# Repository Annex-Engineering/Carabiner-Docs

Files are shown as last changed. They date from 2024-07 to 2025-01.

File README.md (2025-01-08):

# Carabiner

The Carabiner-PCBs are a series of toolboards for a quick & easy connection between the backpack and toolhead.

## Different Variants

| Name | Location | Recommended for Printer | 
| --- | --- | --- |
| Carabiner Classic | Toolhead | Any printer |
| K3rabiner | Toolhead | K3 |
| Carabiner K1.5 | Toolhead | K1 / K2 |
| Carabiner Distributor | Backpack | Any printer
| Carabiner Distributor XOL | Backpack | Any printer with a matching XOL Toolhead Board

As an alternative for any Carabiner in the backpack, you can use a Constellation Sirius (coming soon!) to make wiring your Carabiner even easier!

## Features
All variants of Carabiner share the following main features:
- 16-pin input/output via MicroFit connector
- Chamber thermistor
- USB support
- 48V on your heater, hotend-fan and part-cooling fan (if your mainboard allows for it!)

Most variants of the Carabiner also have the following feature:
- Selectable Voltage for partcooling-fan / hotend-fan between the hotend voltage & 1 alternative voltage

## Warnings

Here be dragons - as with everything that involves electronics, make sure to double-check your wiring before powering it on to avoid producing magic smoke & frying components.  
It's recommended to check the following points:
- Both Carabiners have their MicroFit connector plugged in on the same side of the PCB (usually marked as 'Side A').
- Check for shorts between the following pins with your multimeter:
   - Main+ and HE-
   - Main+ and PCF-
   - Main+ and HEF-
   - Alt+ and PCF-
   - Alt+ and HEF-
   - Alt+ and Main+

## Source, PCBs, Gerbers

While I (iKirin), do enjoy releasing most things that I work/worked on as open-source, I've decided to remove the source as well as the gerbers for all current and future revisions of all carabiners.
This is due to a very limited amount of vendors believing, that just because a source is uploaded to Github, they can take the files and make them, even if commercial use is generally not permitted. 
There is no licensing fee charged for any shop that decides to carry the board, however I do kindly ask that they donate a small amount of money per order to reforestation or local communities dedicated to keep the local flora & fauna intact.

If you want to help to get the carabiner from any shop that is officially affiliated, please check out the [sourcing guide](https://docs.google.com/spreadsheets/d/1O3eyVuQ6M4F03MJSDs4Z71_XyNjXL5HFTZr1jsaAtRc/edit?usp=sharing)

## License

Please see the License.md file in this repo

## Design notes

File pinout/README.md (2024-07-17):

# Pinout

All carabiners (& derivatives) are using the official pinout for the carabiner.

We welcome other groups using the cable for their projects, but kindly ask to note in their project page if they are using the official carabiner pinout, to help prevent damage to users equipment, caused by different pinouts.

## Pinout

This pinout assumes you're looking directly at the cable. 

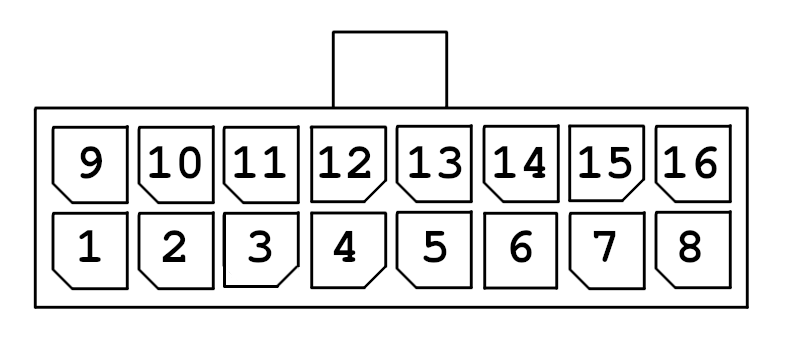
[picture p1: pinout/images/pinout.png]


| PinNumber | Usage  | OnPCB | PinNumber | Usage | OnPCB | 
|---|:---:|:---:| --- |:---:|:---:|
| 1  |  Thermistor Chamber | ThChamb | 9 | Hotend Voltage | Main+
| 2  | Partcooling Fans Ground | PCF- | 10 | Hotend Ground | HE-
| 3  | Hotend Fan Ground | HEF- | 11 | Alt Voltage | Alt+
| 4  | Thermistor Common Ground | ThGnd | 12 | Thermistor Hotend | ThHE
| 5  | Motor A | 1A | 13 | Motor C | 2A
| 6  | Motor B | 1B | 14 | Motor D | 2B
| 7  | Aux 1 | A1 | 15 | Aux 2 | A2
| 8  | Aux 4 | A4 | 16 | Aux 3 | A3

## Recommended Wiregauge

While we have official cables available, we don't want to discourage people making their own cables, as such here is our recommended minimum wiregauge, for making a cable with the official pinout.
These recommendations assume the carabiner is being used in a 50° chamber.

| Pin-Number | Recommended AWG | Recommended mm² |
|:---:|:---:|:---:|
| 1 | 26 | 0.125 |
| 2 | 22 | 0.3 |
| 3 | 26 | 0.125 |
| 4 | 26 | 0.125 |
| 5 | 26 | 0.125 |
| 6 | 26 | 0.125 |
| 7 | 26 | 0.125 |
| 8 | 26 | 0.125 |
| 9 | 22 | 0.3 |
| 10 | 22 | 0.3 |
| 11 | 22 | 0.3 |
| 12 | 26 | 0.125 |
| 13 | 26 | 0.125 |
| 14 | 26 | 0.125 |
| 15 | 26 | 0.125 |
| 16 | 26 | 0.125 |

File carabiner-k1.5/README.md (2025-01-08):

# Carabiner-K1.5

This is a carabiner for either K1 or K2, Rev X.
It has two different versions which only differ by which hotend you're using

## Features

- Input via 16pin horizontal/vertical microfit
- Two outputs for partcooling fans
- Thermistor for the chamber
  - Supports any size from 0603 to 1206

## Other Notes

- Hotend-Fan is always connected to Alt Voltage on Carabiner K1.5
- Partcooling-Fan is always connected to Alt Voltage on Carabiner K1.5

## Connectors & Amperage

_Note: All amperage-values have been designed to work in an enclosed printer with up to 65° chamber temperature & have safety margins. While you could use higher ampere in an open-frame printer, this is not encouraged.<br/>
When multiple connectors are supported **bold** marks the recommended connector._

| | Supported Connectors | Maximum Ampere |
| --- | --- | --- |
| Hotend  | 2-pin JST XH <br/> Microfit 430450227 <br/> **Microfit 436500227** (compatible with e3d heater) | 2 Ampere (40W heater on 24V) <br/> 4.2 Ampere (100W heater on 24V) <br/>4.2 Ampere (100W heater on 24V)
| Hotend Thermistor  | 2-pin JST XH <br/> **Microfit 436500227** (compatible with e3d thermistor) | / <br/> /
| Hotend Fan | 2-pin JST XH | 1 Ampere
| 2x Partcooling Fan | 2-pin JST XH | 1 Ampere (total for both)
| Stepper | 4-pin JST XH | 1.2 Ampere <br/> 0.84 Ampere on TMC drivers as you specify the RMS ampere which is ~70% of peak
| Aux / Probe | 4-pin JST XH | 0.8 Ampere

## BOM / Parts

Links to purchase fully assembled boards can be found here: [ANNEX Sourcing Guide](https://docs.google.com/spreadsheets/d/1aSM1jGxg-s0tyynyR3f8M0IQMXuXw57RJvoJbt98Clw/edit?usp=sharing)

Be aware that the Carabiner K1.5 has 2 options for different hotends.

## Hotends & Versions

<tbd>

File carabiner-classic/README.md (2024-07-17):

# Carabiner-Classic
(Previously known as Carabiner or Carabiner-Toolboard)

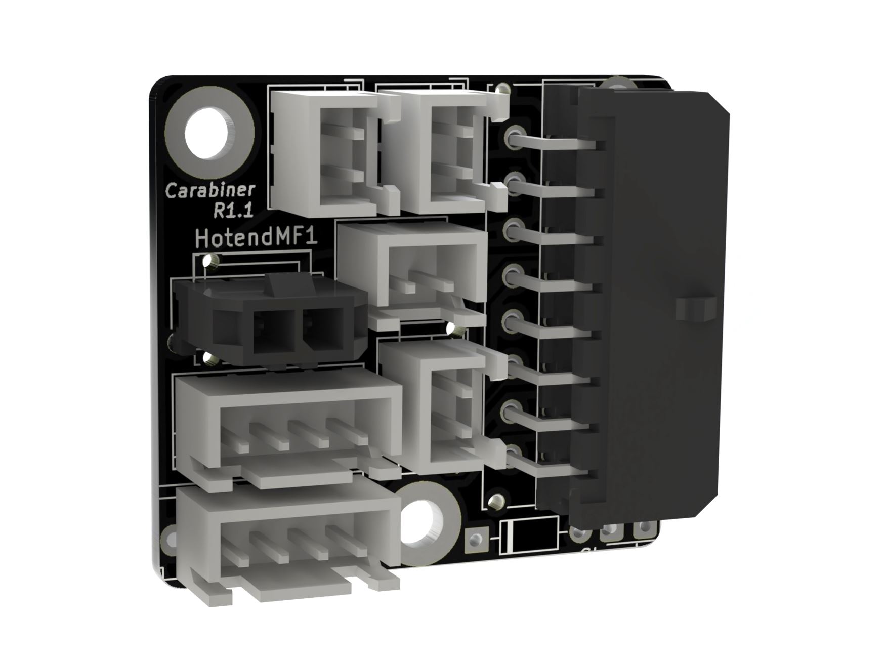
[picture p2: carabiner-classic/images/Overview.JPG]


The carabiner-classic is a toolboard for easy & quick connection between the backpack and toolhead.
It's a generic design, intended to be used a reference and for printers without space constraints.
It was inspired by the first iterations of the dumbboard by LukesLab and designed to bring the idea of a 'simple toolboard' to the next level!

## Features

- Input via 16pin horizontal/vertical microfit
- Two outputs for partcooling fans
- Soldered seperate voltage selection for hotend fan and partcooling fan
   - Uses either the hotend voltage or one alternative voltage
- Thermistor for the chamber
  - Supports any size from 0603 to 1206

## Connectors & Amperage

_Note: All amperage-values have been designed to work in an enclosed printer with up to 65° chamber temperature & have safety margins. While you could use higher ampere in an open-frame printer, this is not encouraged.<br/>
When multiple connectors are supported **bold** marks the recommended connector._

| | Supported Connectors | Maximum Ampere |
| --- | --- | --- |
| Hotend  | 2-pin JST XH <br/> Microfit 430450227 <br/> **Microfit 436500227** (compatible with e3d heater) | 2 Ampere (40W heater on 24V) <br/> 4.2 Ampere (100W heater on 24V) <br/>4.2 Ampere (100W heater on 24V)
| Hotend Thermistor  | 2-pin JST XH <br/> **Microfit 436500227** (compatible with e3d thermistor) | / <br/> /
| Hotend Fan | 2-pin JST XH | 1 Ampere
| 2x Partcooling Fan | 2-pin JST XH | 1 Ampere (total for both)
| Stepper | 4-pin JST XH | 1.2 Ampere <br/> 0.84 Ampere on TMC drivers as you specify the RMS ampere which is ~70% of peak
| Aux / Probe | 4-pin JST XH | 0.8 Ampere

## BOM / Parts

Find the latest BOM in the [Annex Sourcing Guide](https://docs.google.com/spreadsheets/d/1O3eyVuQ6M4F03MJSDs4Z71_XyNjXL5HFTZr1jsaAtRc) under PCBs

## Revisions

The following revisions have been made to the Carabiner-Classic (Previously known as Carabiner).
This overview is non-exhaustive and does not cover all revisions that were previously released.

|Version|Changes|Known Bugs|
|:---|:-----|:---|
|1.3|Remove 5th pin for AUX.<br>Add USB-support on the AUX-port|-|
|1.2.1|-|The second A3 port, after JP_A3 is not connected.|
|1.2|-|The second A3 port, after JP_A3 is not connected.|

## Build Guide

[Please check out this simple written build guide](buildguide/README.md).

## Wiring Guide

[Please refer to the pinout-section of the docs](../pinout/README.md)

## Gallery
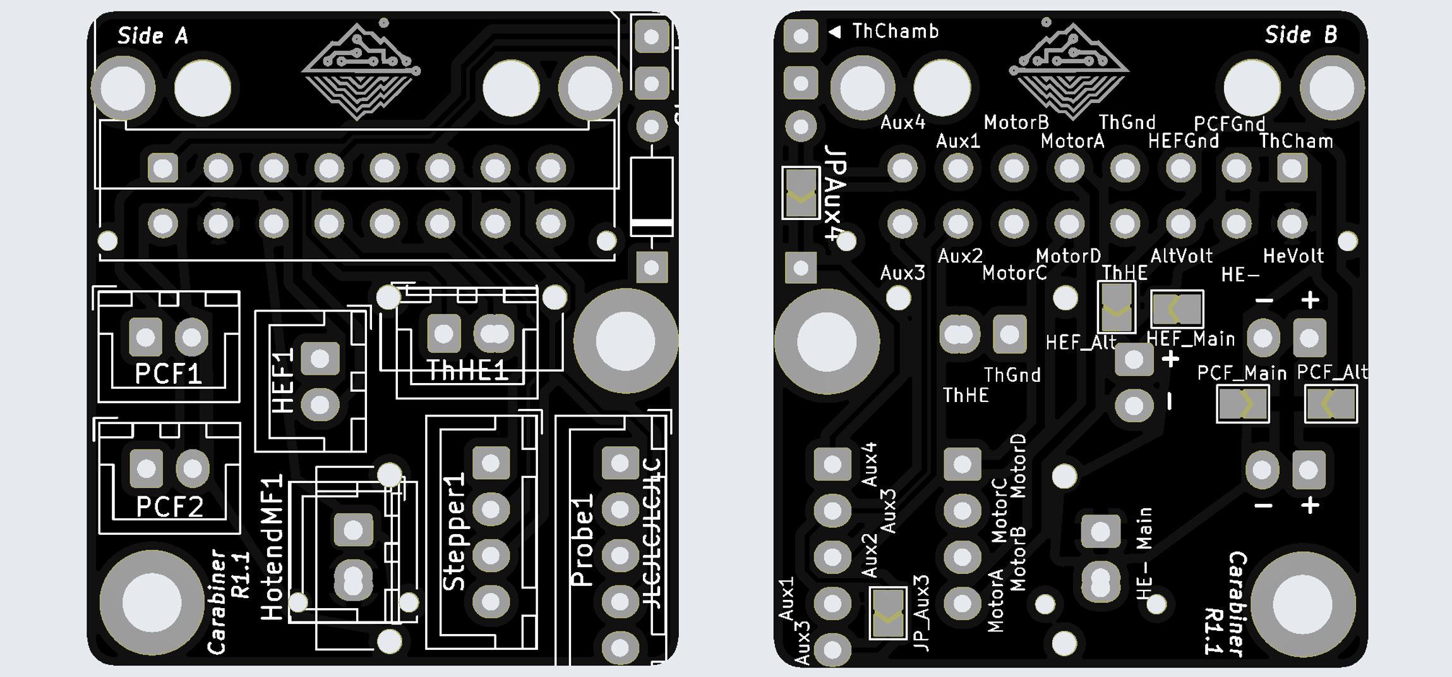
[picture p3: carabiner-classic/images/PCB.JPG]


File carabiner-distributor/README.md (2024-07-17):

# Carabiner Distributor

The distributor variant is a toolboard for the electronics bay providing an easy & quick connection between the electronic controllers and toolhead. 
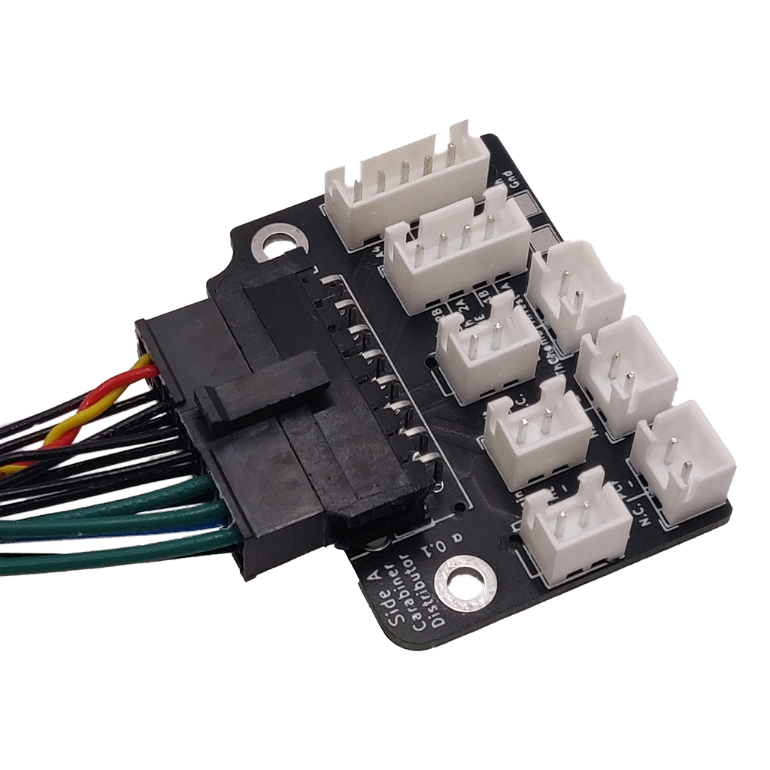
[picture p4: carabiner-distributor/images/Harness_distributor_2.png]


## Features

- Input via 16pin horizontal or vertical microfit
- Testpads for easy thermistor troubleshooting
- Easy to read labeling of the connectors

## Connectors & Amperage

_Note: All amperage-values have been designed to work in an enclosed printer with up to 65° chamber temperature & have  some safety margins. While you could use higher ampere in an open-frame printer, it's highly discouraged. <br/>
When multiple connectors are supported **bold** marks the recommended connector._

| | Supported Connectors | Maximum Ampere |
| --- | --- | --- |
| Hotend  | 2-pin JST XH <br/> Microfit 430450227 <br/> **Microfit 436500227** (compatible with e3d heater) | ~2 Ampere (50W heater on 24V) <br/> 4.2 Ampere (100W heater on 24V) <br/>4.2 Ampere (100W heater on 24V)
| Hotend Thermistor  | 2-pin JST XH <br/> **Microfit 436500227** (compatible with e3d thermistor) | / <br/> /
| Hotend Fan | 2-pin JST XH | 1 Ampere
| Partcooling Fan | 2-pin JST XH | 2 Ampere
| Stepper | 4-pin JST XH | 1.2 Ampere <br/> 0.84 Ampere on TMC drivers as you specify the RMS ampere which is ~70% of peak
| Aux / Probe | 4 or 5-pin JST XH | 0.8 Ampere

## Sourcing

Links to purchase fully assembled boards can be found here: [ANNEX Sourcing Guide](https://docs.google.com/spreadsheets/d/1aSM1jGxg-s0tyynyR3f8M0IQMXuXw57RJvoJbt98Clw/edit?usp=sharing)

Be aware that the distributor pcb has 2 options for connectors regarding the thermistor and heater.

## Using the Testpads

When using both the hotend and chamber thermistor, it is important to ensure that you don't accidentially have the Ground swapped with the Thermistor-Pin.
To validate your thermistors are wired up correctly, it's recommended to use a multimeter and the Testpads on the Distributor.
Connect the Distributor to the mainboard of the printer.
When everything is wired up correctly, the resistance between the two Testpads should be close to 0 Ohms. 
If it does not measure 0 Ohms, please check your wiring and ensure that both ThTest as well as ThGnd are wired to the ThermistorGnd on the mainboard of your printer.

## Revisions

The following revisions have been made to the Carabiner Distributor.
This overview is non-exhaustive and does not cover all revisions that were previously released.

|Version|Changes|Known Bugs|
|:---|:-----|:---|
|1.0|-|-|

## Wiring Guide

[Please refer to the pinout-section of the docs](../pinout/README.md)

## Dimensions
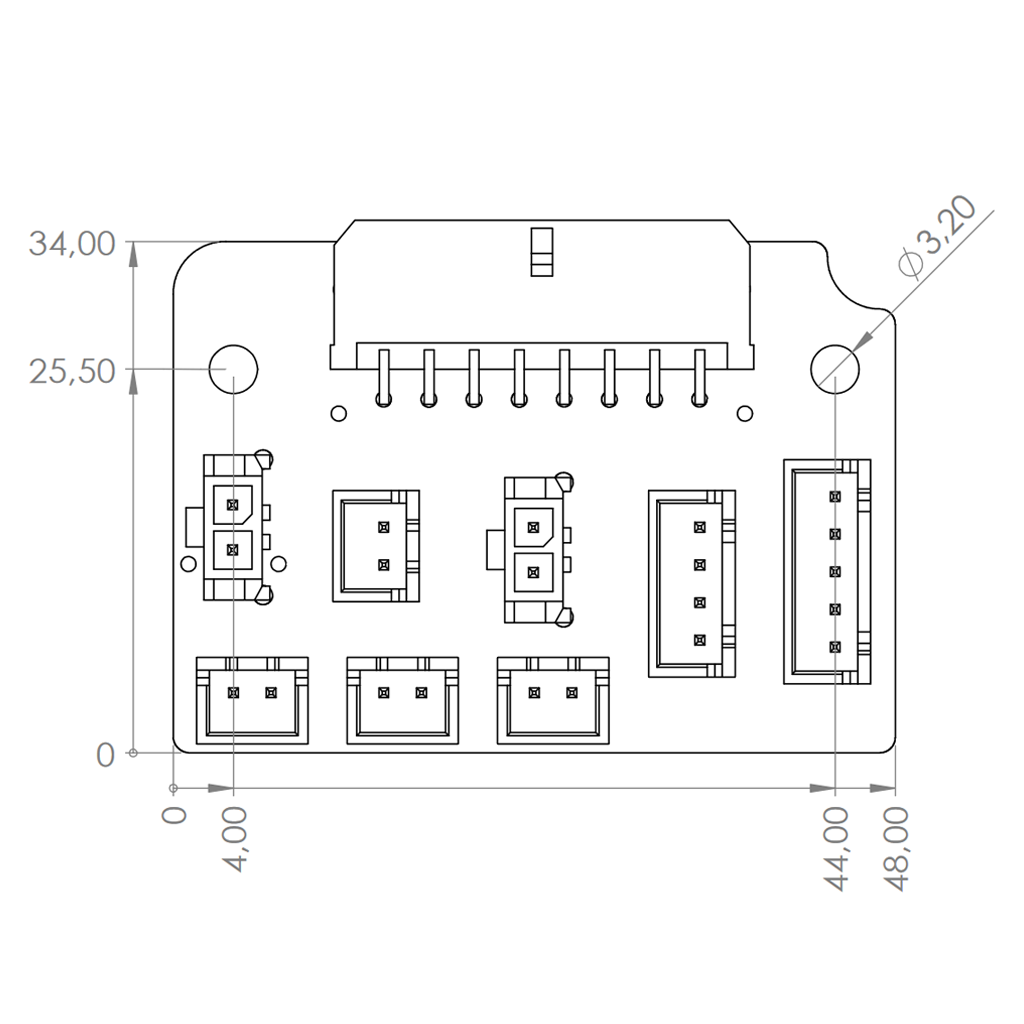
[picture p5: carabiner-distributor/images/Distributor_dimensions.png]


## Gallery
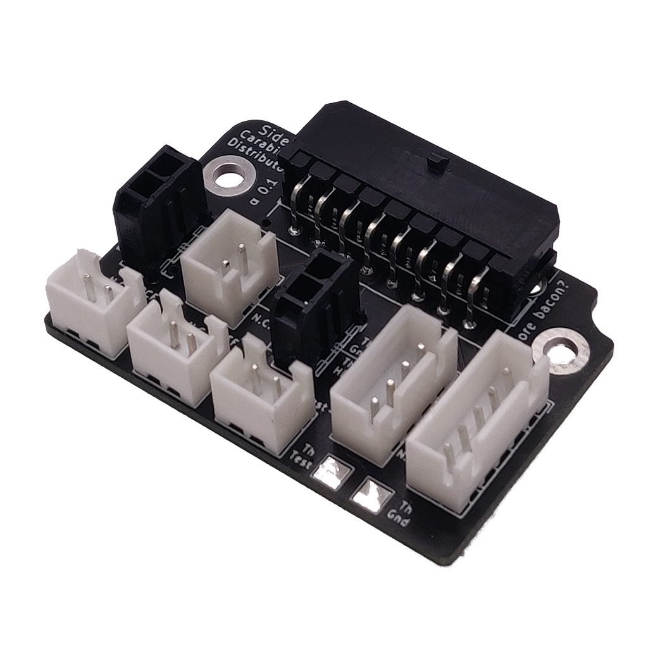
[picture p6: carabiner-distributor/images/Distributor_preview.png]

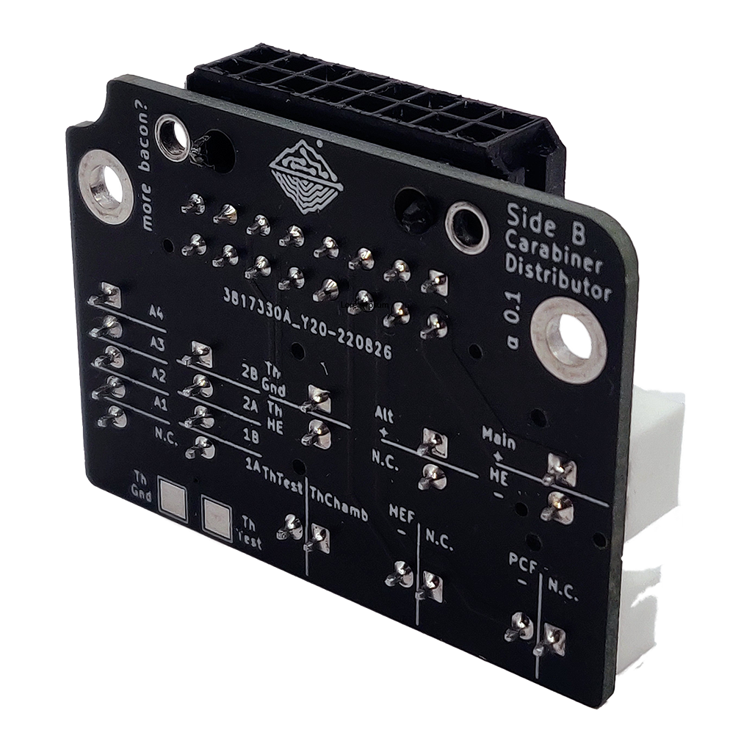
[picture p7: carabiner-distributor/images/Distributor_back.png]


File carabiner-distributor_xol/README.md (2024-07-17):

# Carabiner Distributor XOL

The distributor for the XOL toolboard. 
Be warned that this does not use the official carabiner pinout, and as such can cause damage to your electronics, unless used with the XOL toolboard.

## Features

- Input via 16pin horizontal or vertical microfit
- Testpads for easy thermistor troubleshooting
- Easy to read labeling of the connectors

## Connectors & Amperage

_Note: All amperage-values have been designed to work in an enclosed printer with up to 65° chamber temperature & have  some safety margins. While you could use higher ampere in an open-frame printer, it's highly discouraged. <br/>
When multiple connectors are supported **bold** marks the recommended connector._

| | Supported Connectors | Maximum Ampere |
| --- | --- | --- |
| Hotend  | 2-pin JST XH <br/> Microfit 430450227 <br/> **Microfit 436500227** (compatible with e3d heater) | ~2 Ampere (50W heater on 24V) <br/> 4.2 Ampere (100W heater on 24V) <br/>4.2 Ampere (100W heater on 24V)
| Hotend Thermistor  | 2-pin JST XH <br/> **Microfit 436500227** (compatible with e3d thermistor) | / <br/> /
| Hotend Fan | 2-pin JST XH | 1 Ampere
| Partcooling Fan | 2-pin JST XH | 2 Ampere
| Stepper | 4-pin JST XH | 1.2 Ampere <br/> 0.84 Ampere on TMC drivers as you specify the RMS ampere which is ~70% of peak
| Aux / Probe | 4 or 5-pin JST XH | 0.8 Ampere

## Sourcing

Links to purchase fully assembled boards can be found here: [ANNEX Sourcing Guide](https://docs.google.com/spreadsheets/d/1aSM1jGxg-s0tyynyR3f8M0IQMXuXw57RJvoJbt98Clw/edit?usp=sharing)

Be aware that the distributor pcb has 2 options for connectors regarding the thermistor and heater.

## Using the Testpads

When using both the hotend and chamber thermistor, it is important to ensure that you don't accidentially have the Ground swapped with the Thermistor-Pin.
To validate your thermistors are wired up correctly, it's recommended to use a multimeter and the Testpads on the Distributor.
Connect the Distributor to the mainboard of the printer.
When everything is wired up correctly, the resistance between the two Testpads should be close to 0 Ohms. 
If it does not measure 0 Ohms, please check your wiring and ensure that both ThTest as well as ThGnd are wired to the ThermistorGnd on the mainboard of your printer.

## Revisions

The following revisions have been made to the Carabiner Distributor.
This overview is non-exhaustive and does not cover all revisions that were previously released.

|Version|Changes|Known Bugs|
|:---|:-----|:---|
|1.0|-|-|

## Wiring Guide

_Be warned that this does not use the official carabiner pinout, and as such can cause damage to your electronics, unless used with the XOL toolboard._

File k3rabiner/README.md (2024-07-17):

# K3rabiner-Toolboard

The K3rabiner is a customized toolboard for the K3 and an easy & quick connection between the backpack and toolhead. Thanks to wendemann for the original work & inspiration.
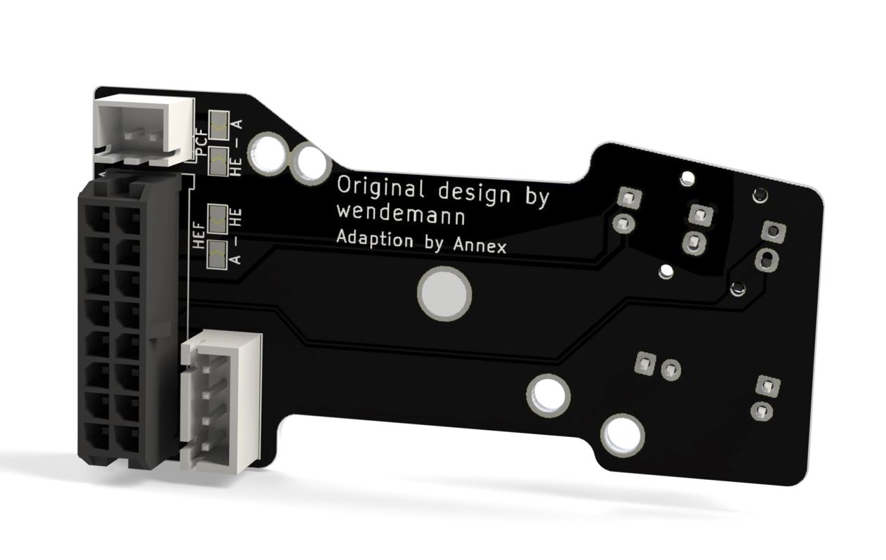
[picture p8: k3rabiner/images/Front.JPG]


## Features

- Supports Sherpa Mini/Micro ONLY
- Input via 16pin horizontal microfit
- Output for partcooling fans
- Soldered seperate voltage selection for hotend fan and partcooling fan
   - Uses either the hotend voltage or one alternative voltage

## Connectors & Amperage

_Note: All amperage-values have been designed to work in an enclosed printer with up to 65° chamber temperature & have  some safety margins. While you could use higher ampere in an open-frame printer, it's highly discouraged. <br/>
When multiple connectors are supported **bold** marks the recommended connector._

| | Supported Connectors | Maximum Ampere |
| --- | --- | --- |
| Hotend  | 2-pin JST XH <br/> Microfit 430450227 <br/> **Microfit 436500227** (compatible with e3d heater) | ~2 Ampere (50W heater on 24V) <br/> 4.2 Ampere (100W heater on 24V) <br/>4.2 Ampere (100W heater on 24V)
| Hotend Thermistor  | 2-pin JST XH <br/> **Microfit 436500227** (compatible with e3d thermistor) | / <br/> /
| Hotend Fan | 2-pin JST XH | 1 Ampere
| Partcooling Fan | 2-pin JST XH | 2 Ampere
| Stepper | 4-pin JST XH | 1.2 Ampere <br/> 0.84 Ampere on TMC drivers as you specify the RMS ampere which is ~70% of peak
| Aux / Probe | 4-pin JST XH | 0.8 Ampere

## BOM / Parts

Find the latest BOM in the [Annex Sourcing Guide](https://docs.google.com/spreadsheets/d/1O3eyVuQ6M4F03MJSDs4Z71_XyNjXL5HFTZr1jsaAtRc) under PCBs

## Revisions

The following revisions have been made to the K3rabiner.
This overview is non-exhaustive and does not cover all revisions that were previously released.

|Version|Changes|Known Bugs|
|:---|:-----|:---|
|1.0|-|-|

## Build Guide

[Please check out this simple written build guide](buildguide/README.md).

## Wiring Guide

[Please refer to the pinout-section of the docs](../pinout/README.md)

## Gallery
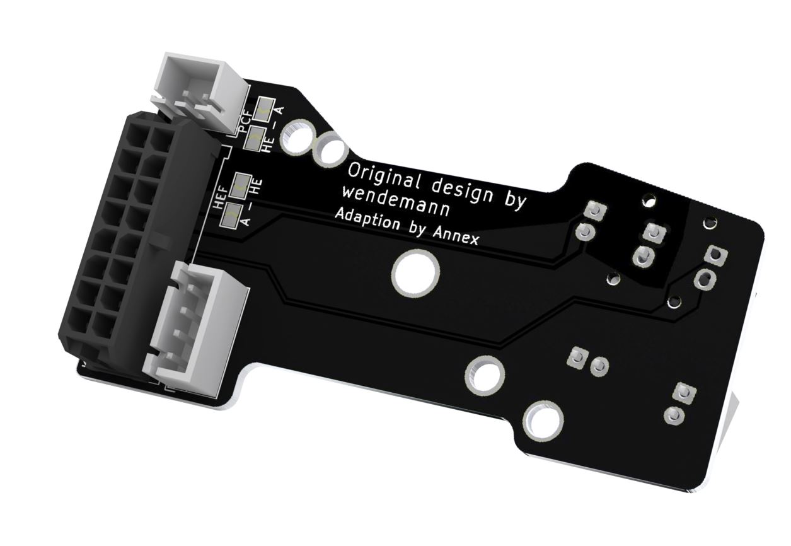
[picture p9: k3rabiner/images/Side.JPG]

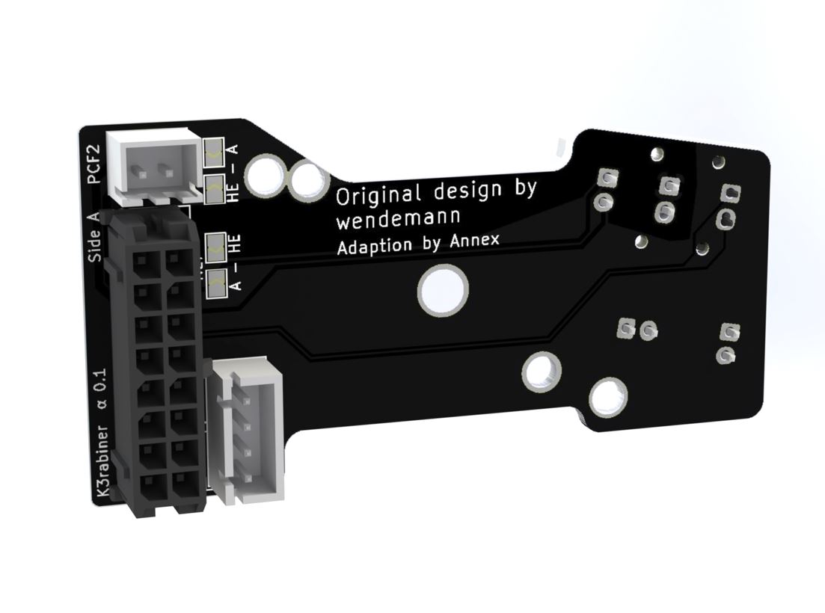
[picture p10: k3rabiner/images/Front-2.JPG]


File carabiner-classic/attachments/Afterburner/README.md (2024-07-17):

## Carabiner PCB for the Afterburner toolhead

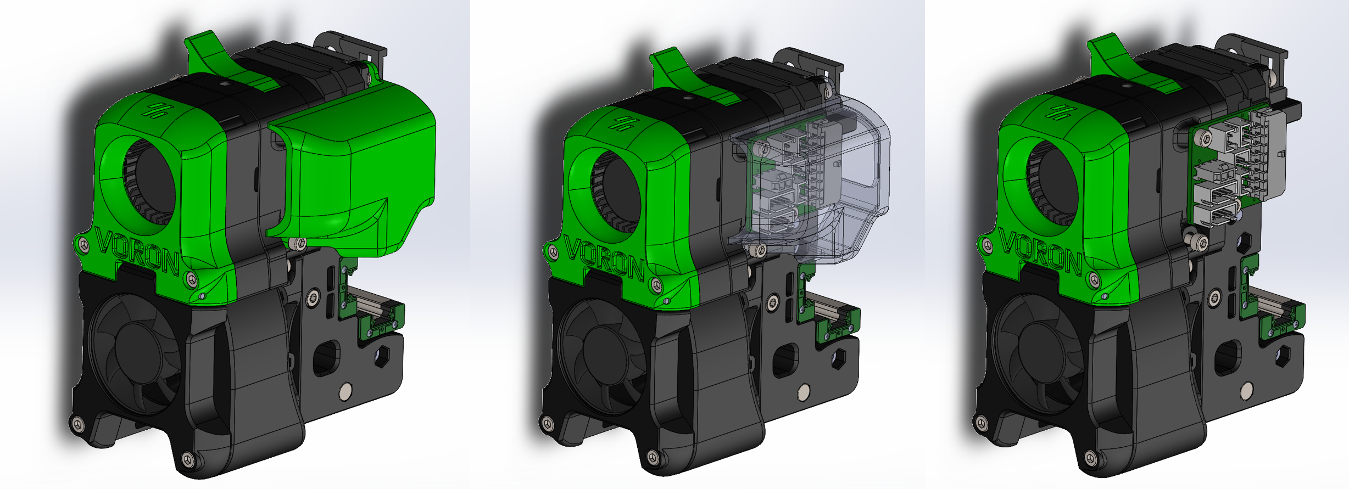
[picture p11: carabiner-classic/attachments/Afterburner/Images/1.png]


## What is it?
This mod adds support to mount the carabiner PCB directly to the Afterburner Clockwork. This allows you to up you cable management and quickly swap components whenever wanted. A PCB cover is also included when desired and full x and y travel is possible. Additionally the chamber temperature can be measured with the on board thermistor. Many safety calculations have been done on the PCB to ensure safe operation within a closed chamber. For the max current on each channel check the [table](https://github.com/Annex-Engineering/Annex_Engineering_PCBs/tree/master/carabiner-toolboard). 

## Hardware needed:
- 3x M3x5x4 heatinserts
- 3x DIN912 M3x6

## Resources
Carabiner: https://github.com/Annex-Engineering/Annex_Engineering_PCBs/tree/master/carabiner-toolboard

## Gallery
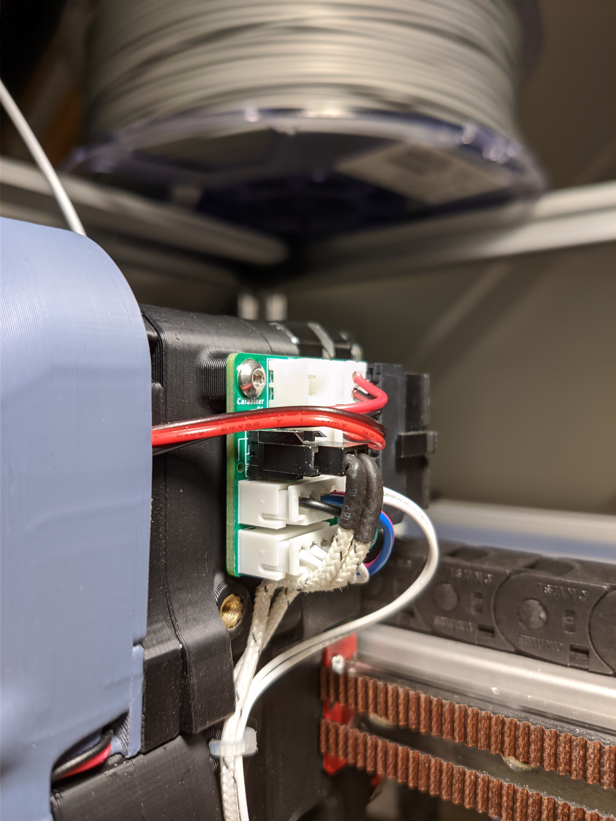
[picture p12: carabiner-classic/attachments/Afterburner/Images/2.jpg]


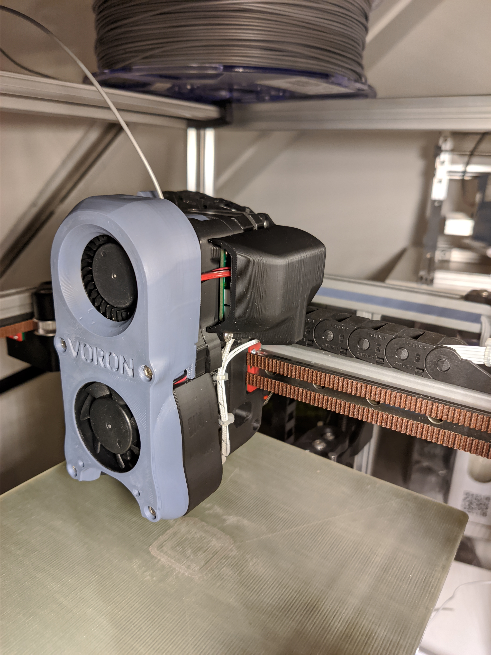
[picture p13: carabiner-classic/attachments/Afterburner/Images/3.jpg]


## Discord
Do you have any design suggestions or ideas? We would love to hear! You can join us at https://discord.gg/MzTR3zE

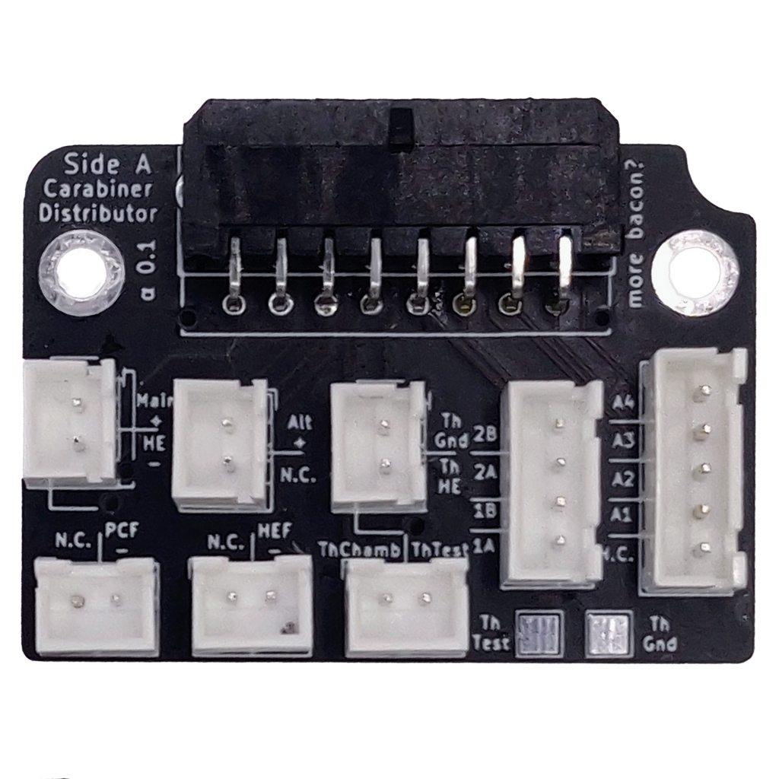
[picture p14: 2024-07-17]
carabiner-distributor/images/Distributor_jstxh.png

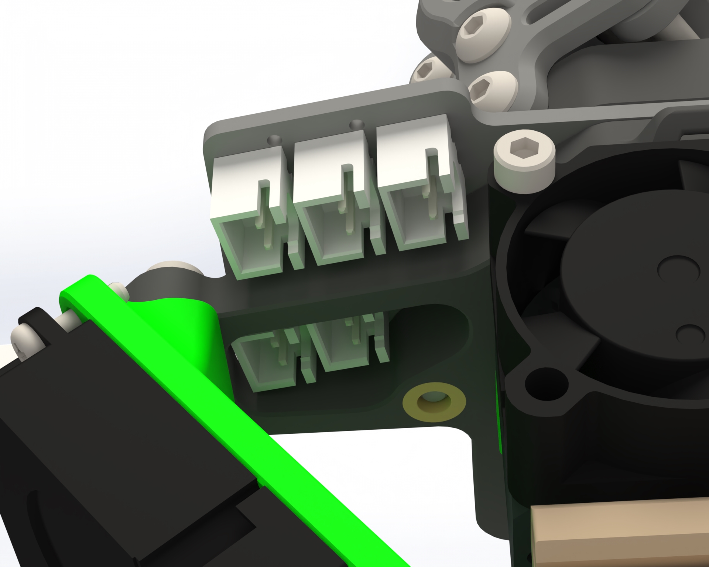
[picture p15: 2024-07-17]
k3rabiner/images/Untitled Project 42.jpg

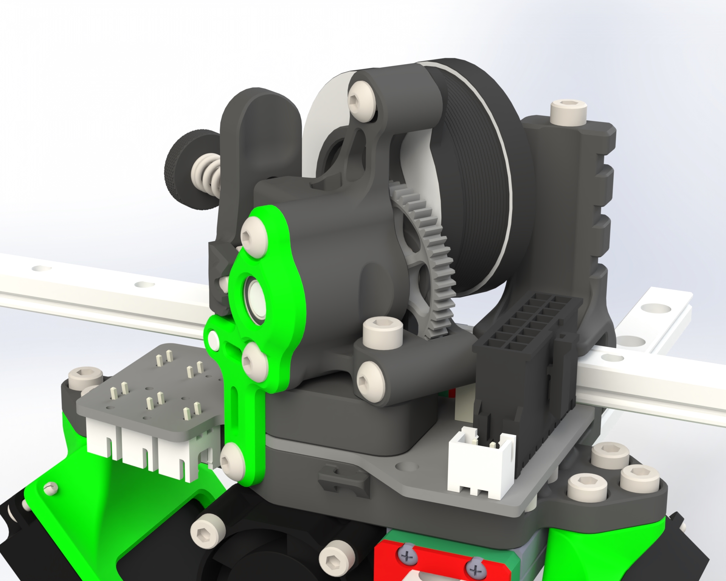
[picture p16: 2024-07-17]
k3rabiner/images/Micro 2.jpg

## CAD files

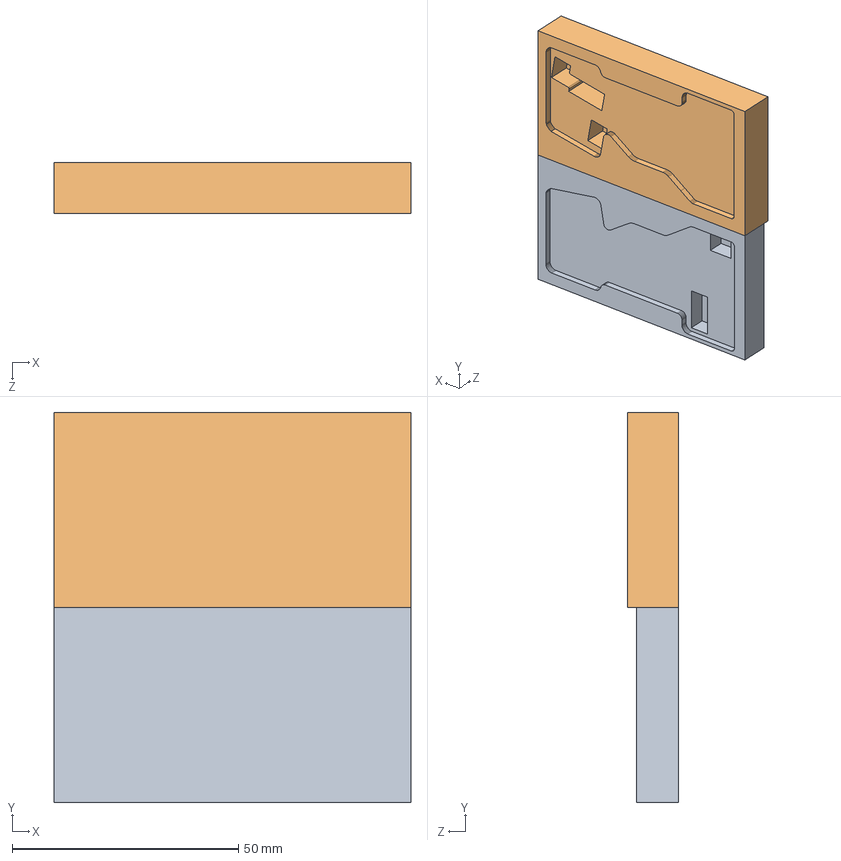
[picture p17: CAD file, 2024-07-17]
k3rabiner/Soldering_Jig_R1/Assem1.SLDASM
78.8 x 86.1 x 11.2 mm
k3rabiner-b_0_1-Jig_Top
k3rabiner-b_0_1-Jig_Bottom

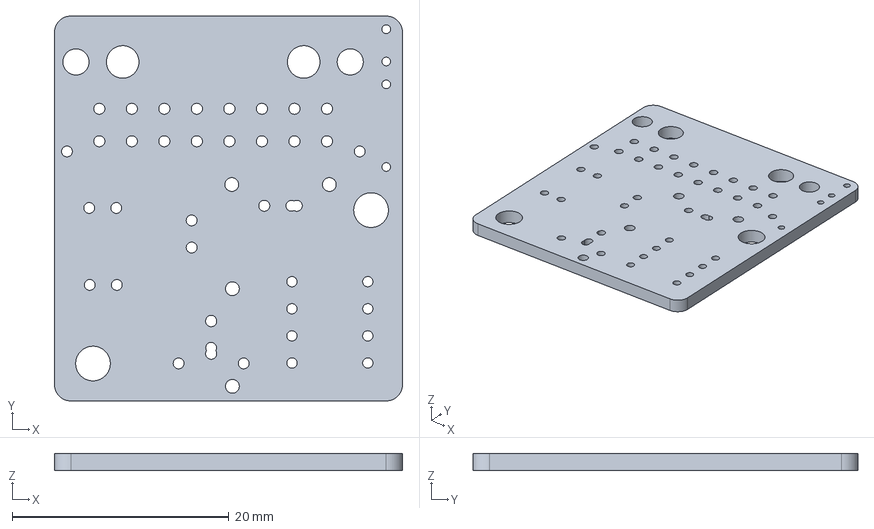
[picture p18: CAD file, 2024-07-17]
carabiner-classic/3d-models/STEPs/carabiner-r1-unpopulated.step
32.1 x 35.5 x 1.60 mm

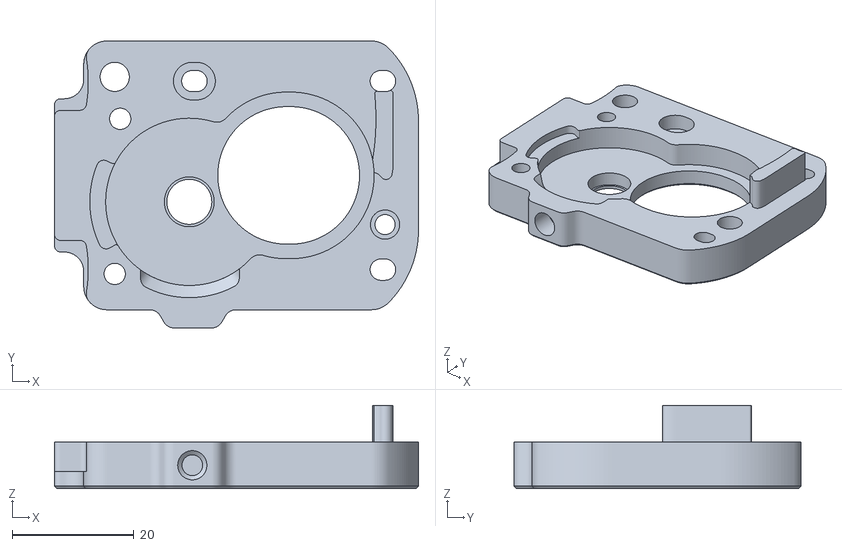
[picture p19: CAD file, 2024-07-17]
carabiner-classic/attachments/Afterburner/STLs/Clockwork_backplate_x1_Rev1.STL
59.9 x 47.2 x 13.7

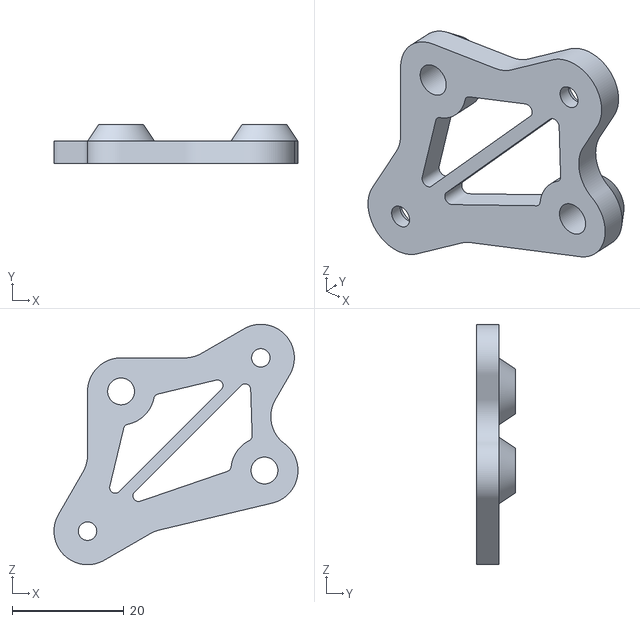
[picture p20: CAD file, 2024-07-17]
carabiner-classic/attachments/NEMA17-bracket/Carabiner-Nema17-Bracket.stl
43.6 x 7.00 x 43.0

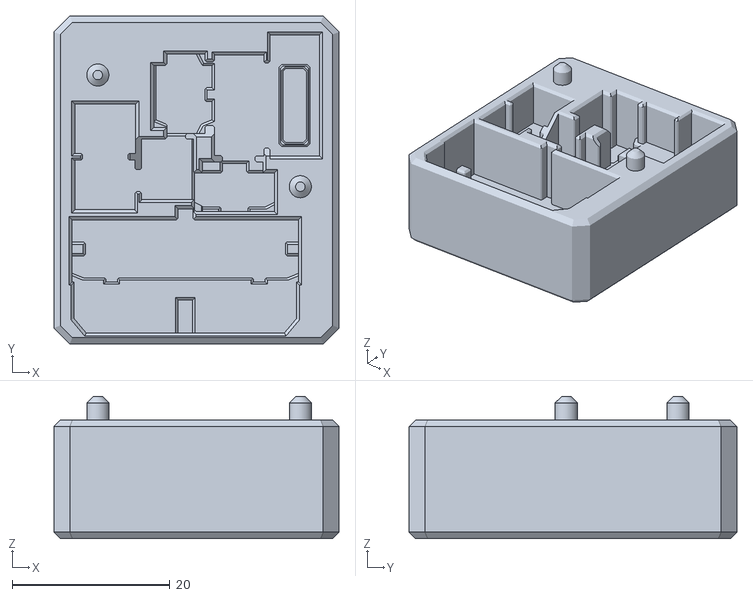
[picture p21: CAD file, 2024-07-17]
carabiner-classic/soldering_jig/carabiner-r1-soldering-jig.stl
36.1 x 41.5 x 18.0

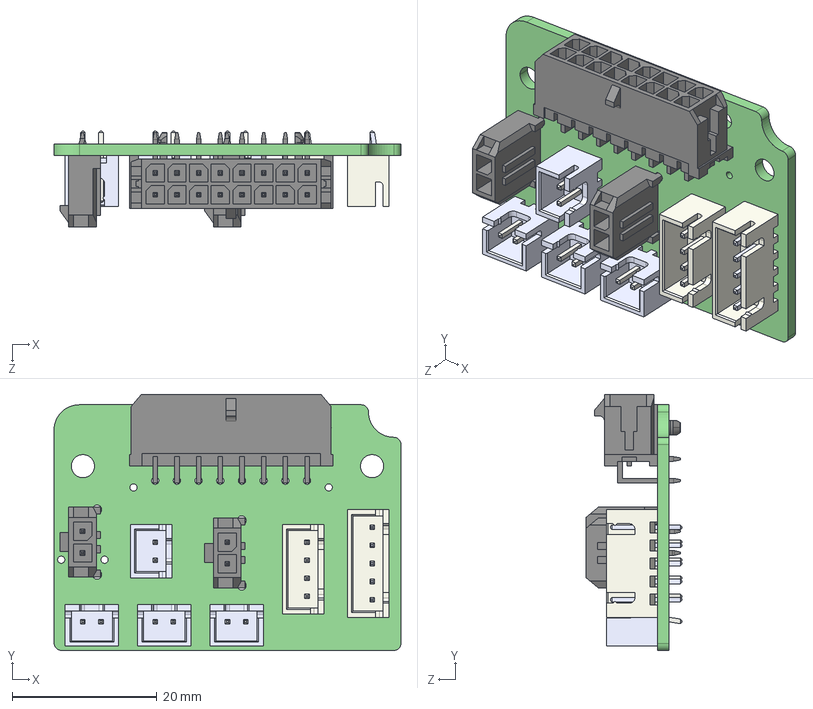
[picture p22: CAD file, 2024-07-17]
carabiner-distributor/cad/carabiner_distro.STEP
48.0 x 35.4 x 13.3 mm
carabiner-distributor PCB

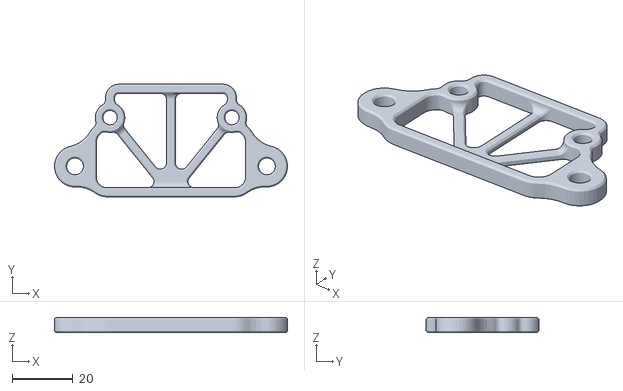
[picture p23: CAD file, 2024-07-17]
carabiner-distributor/stls/carabiner_distribution_mounting_bracket_x1_rev1.STL
76.5 x 37.0 x 5.00

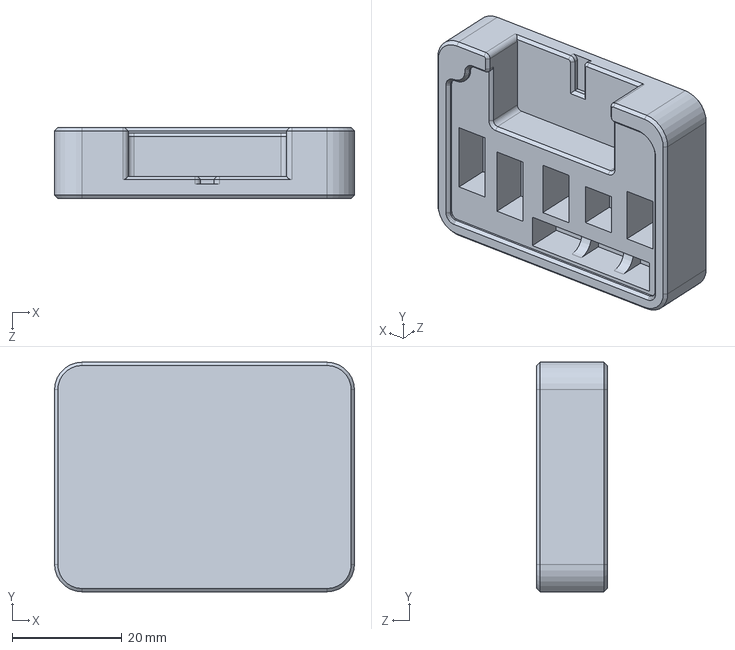
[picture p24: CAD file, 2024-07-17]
carabiner-distributor_xol/assembly_jig/carabiner_distro_r1.SLDPRT
54.6 x 41.8 x 12.9 mm

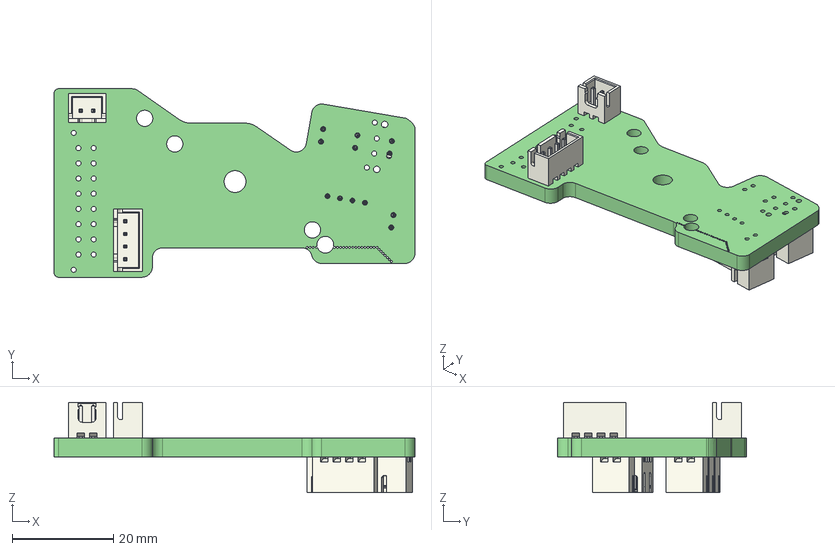
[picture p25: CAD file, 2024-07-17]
k3rabiner/CAD/Beta_1/k3rabiner-b_0_1.step
71.2 x 37.2 x 17.8 mm
k3rabiner PCB

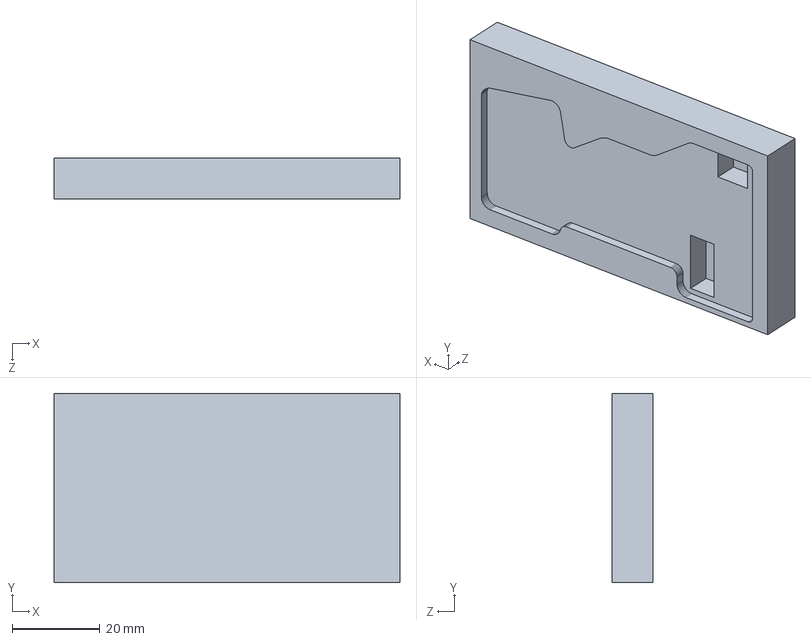
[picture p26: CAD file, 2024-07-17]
k3rabiner/Soldering_Jig_R1/k3rabiner-b_0_1-Jig_Top.SLDPRT
78.8 x 43.1 x 9.25 mm

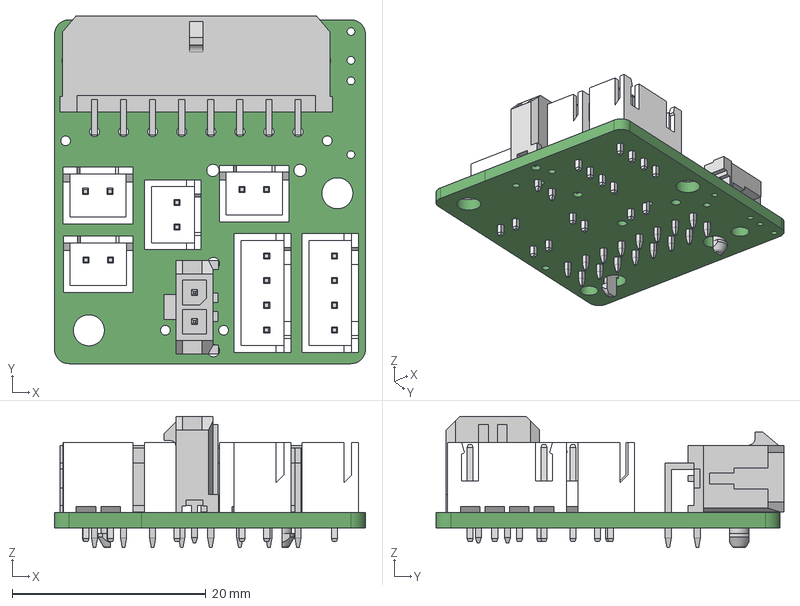
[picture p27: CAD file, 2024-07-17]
carabiner-classic/3d-models/STEPs/carabiner-r1-populated.step
32.1 x 35.9 x 13.5 mm
JST - XH - Thru (V) - 2Pin - 2.54mm x 4
JST - XH - Thru (V) - 4Pin - 2.54mm x 2
Molex Micro-Fit 16pin horizontal (MicroFit)

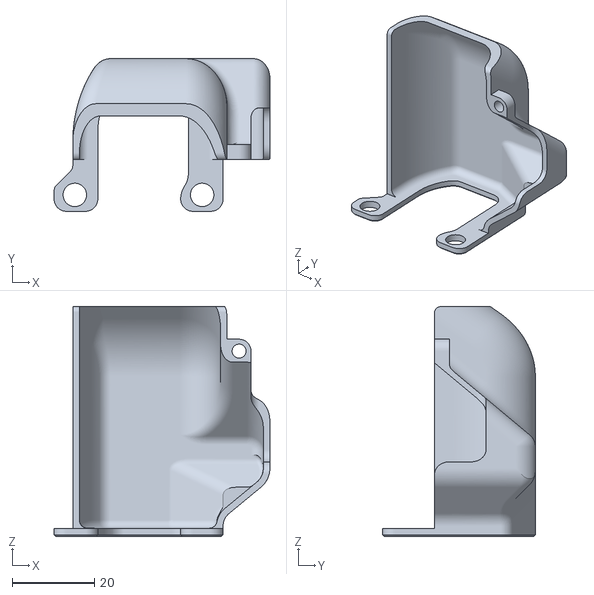
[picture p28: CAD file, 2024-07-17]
carabiner-classic/attachments/Afterburner/STLs/PCB_cover_Microfit_x1_Rev1.STL
52.6 x 37.2 x 56.0

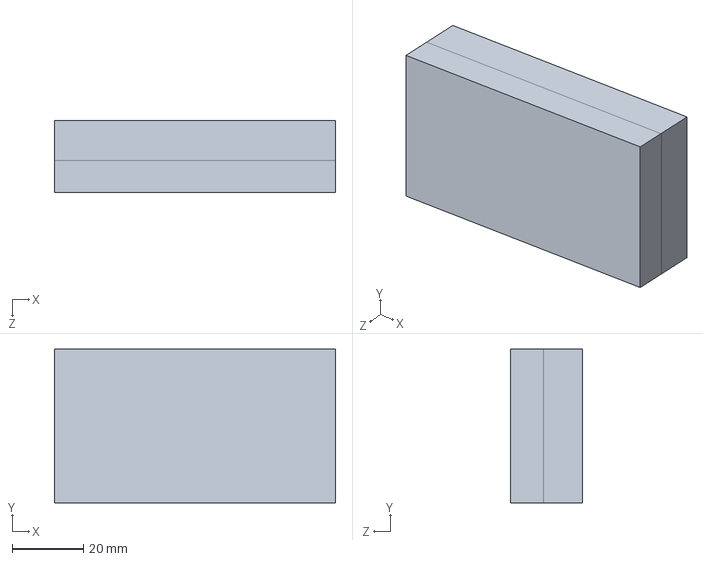
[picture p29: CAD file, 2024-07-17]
k3rabiner/Soldering_Jig_R1/k3rabiner-b_0_1.SLDPRT
78.8 x 43.1 x 20.1 mm

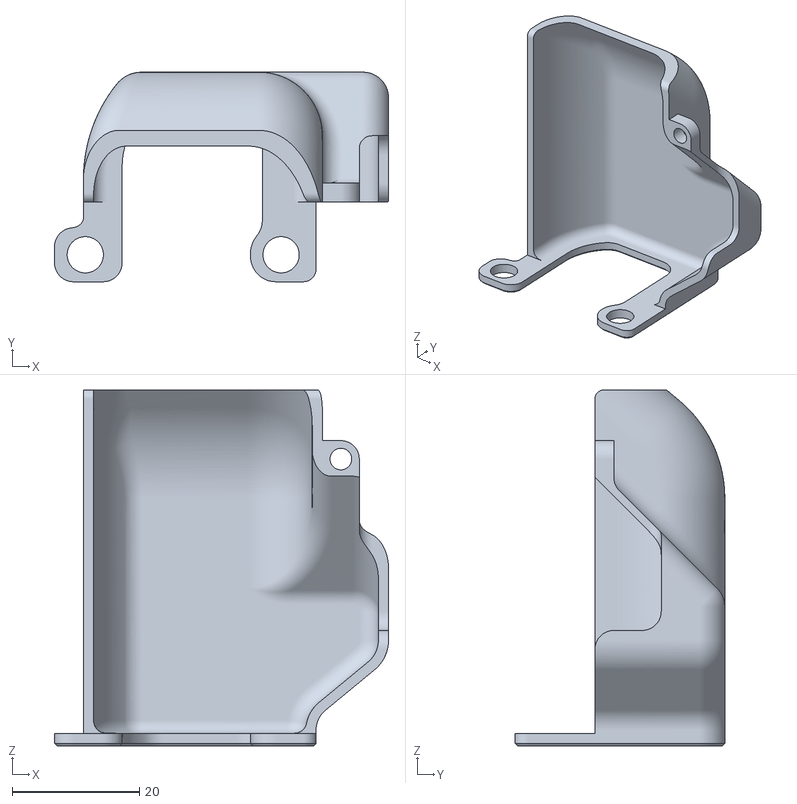
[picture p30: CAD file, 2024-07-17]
carabiner-classic/attachments/Afterburner/STLs/PCB_cover_JST-XH_x1_Rev1.STL
52.6 x 33.0 x 56.0

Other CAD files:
k3rabiner/Soldering_Jig_R1/k3rabiner-b_0_1_XH_Soldering_Jig.SLDPRT
carabiner-classic/attachments/Afterburner/STLs/Clockwork_housing_x1_Rev1.STL
k3rabiner/Soldering_Jig_R1/k3rabiner-b_0_1-Jig_Bottom.SLDPRT
carabiner-classic/3d-models/Parasolids/carabiner-r1-populated.x_t
carabiner-classic/3d-models/Parasolids/carabiner-r1-unpopulated.x_t
carabiner-classic/attachments/Afterburner/CAD/Main_body_VORON_Clockwork.x_t
carabiner-classic/attachments/Afterburner/CAD/Motor_plate_VORON_Clockwork.x_t
carabiner-classic/attachments/Afterburner/CAD/PCB_cover_JST-XH_x1_Rev1.x_t
carabiner-classic/attachments/Afterburner/CAD/PCB_cover_Microfit_x1_Rev1.x_t
carabiner-classic/soldering_jig/carabiner-r1-soldering-jig.x_t
carabiner-distributor_xol/assembly_jig/carabiner_distro_r1.STL
k3rabiner/Soldering_Jig_R1/k3rabiner-b_0_1_XH_Soldering_Jig.STL

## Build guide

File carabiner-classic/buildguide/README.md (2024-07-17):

# Build Guide

This build guide is showing how to solder together your Carabiner.  
It's only showing how to assemble a regular Carabiner PCB, however all current 
and future variants of the carabiner should be similar in how to assemble them.

## Step 1 - Choose a side

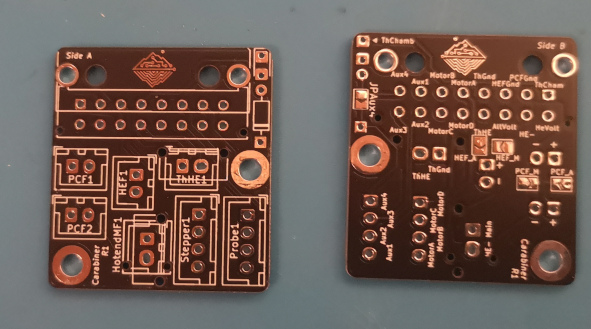
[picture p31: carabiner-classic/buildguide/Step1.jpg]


Your Carabiner PCB should be marked with 'Side A' and 'Side B' on either the left or right top.
While you can install the 16-pin microfit connector on either side, we recommend putting it on 'Side A' as shown in this build-guide to be compatible with most versions of the carabiner.

:x: | If you use one carabiner PCB on your toolhead and one on your controller side, make sure that the connector is installed on the same Side for both PCBs!
:---: | :---
:information_source: | __It is recommended to install your microfit on 'Side A' as some variants of the carabiner might support one side only - and this is 'Side A' by default.__

## Step 2 - Connectors, assemble!

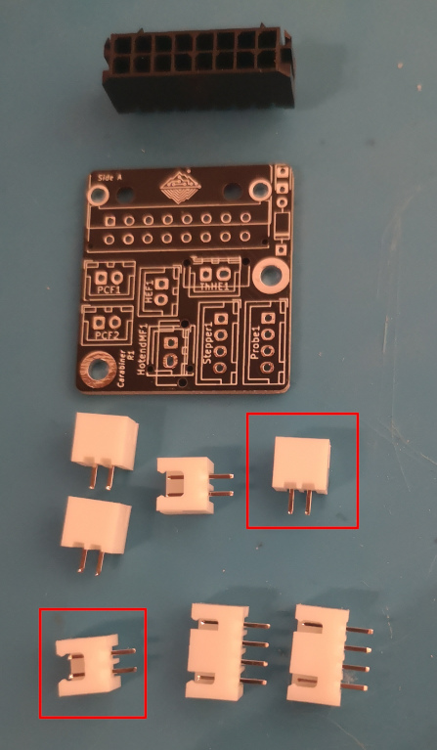
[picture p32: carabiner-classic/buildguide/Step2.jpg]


The Carabiner PCB uses mostly JST XH connectors with either 2 or 4 pins. However, for the hotend and thermistor (marked in the picture bottom left and top right respectively) you can also choose to use different connectors.  
Please check [this overview for supported connectors](../README.md#connectors--amperage).

## Step 2.1 - (Optional) Chamber Thermistor and BAT-Diode 

This is an optional step.  
If you intend to use the chamber thermistor or a BAT-diode for an inductive Z-probe on the AUX-connection, it is recommended to solder them on now before any connectors are included.

## Step 3 - Soldering the connectors

Solder up all the connectors, excluding the 16-pin microfit.  
Take your time and make sure that all connectors have a good solid connection.

:information_source: | If you're having a hard time with the PCB wobbling when trying to solder on the connectors, we recommend using a printed spacer, around 7mm tall.
:---: | :---

## Step 4 - Power to the fans

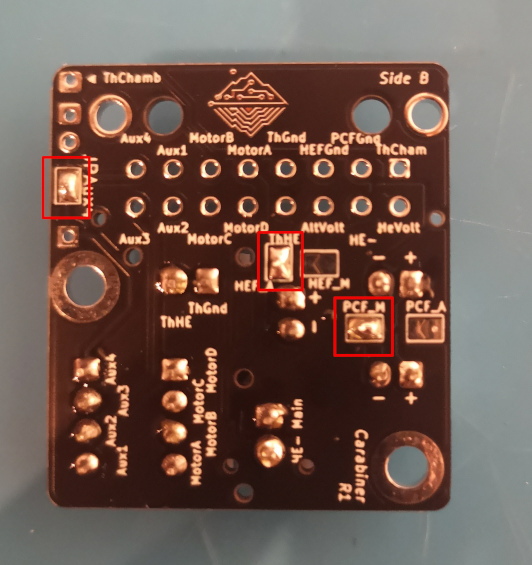
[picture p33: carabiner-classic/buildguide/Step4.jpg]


It is now time to select the voltage for your fans. Check your hotend fan and partcooling fans respectively. They should both either require your hotend voltage or alt voltage.  
Solder the jumper for the required voltage - in this build-guide the hotend-fan requires the 'altVoltage' while the partcooling-fans require hotend voltage.  
If you did not install a BAT-Diode in Step 2.1 please also solder the JPAux4, shown in the top-right of the image.

:information_source: | Ensure that you select the voltage correctly for the hotend fan as well as the partcooling fans. 
:---: | :---
:warning: | __It is not possible to have your hotend fan or partcooling fan running with a different voltage than HotendVoltage or AltVoltage.__

## Step 5 - Connection established

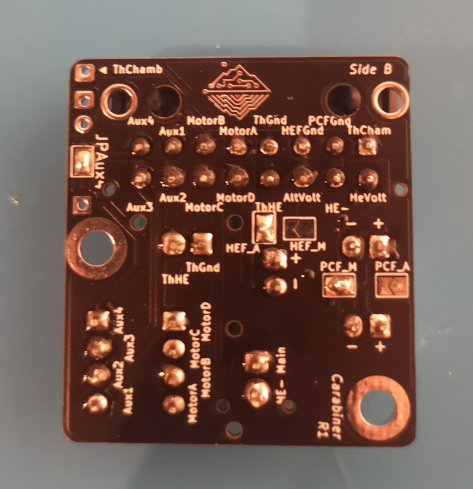
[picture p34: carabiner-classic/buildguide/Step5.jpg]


After all previous steps, it is now time to solder up the 16-pin microfit connector. Place it on the side you want it to have (Side A in this example) and ensure that if latches are present, they click into the PCB.  
Then solder all 16 connections.

If wanted, you can check your soldering connections with a multimeter.  
__Congratulations__, you have now built your very own Carabiner PCB. Be proud of yourself, wire up your carabiner to your controller and __happy printing__

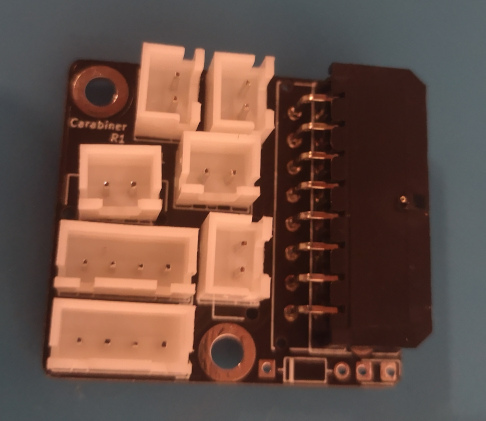
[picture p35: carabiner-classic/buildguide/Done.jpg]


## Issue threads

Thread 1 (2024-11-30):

[ERROR] Distribution Board XOL Toolhead errors on silkscreen of PCB in relationship with documentation

roykrikke, 2024-11-30:
I have found some mistakes in the distribution Board XOL toolhead related to silkscreen of PCB in relationship with documentation.

See picture below:
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
